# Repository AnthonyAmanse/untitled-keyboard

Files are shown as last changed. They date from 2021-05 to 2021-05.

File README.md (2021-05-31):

# Untitled Keyboard

This is a choc only wireless split keyboard with pro micro compatible sockets. It's inspired by the Sofle, Lily58, Corne, ... keyboards. It has Kailh choc spacings (18 mm x 17 mm). Keycaps I'm using are MBK choc keycaps which has a size of 17.5 x 16.5. I didn't add support for encoder to make it a bit lighter. Pinky columns has a 0.5u vertical offset to make it more comfortable (at least for me). Bottom row has 2 x 1.5u keys with an angle. I thought this would make the thumb cluster more comfortable and reachable. In my experience with this keyboard, the thumb keys are more comfortable when the keyboard is tented. OLED is supported as well - make sure you have a big battery as it consumes a lot of power. I'm using 2000 mAh. This should last me 3-4 weeks based on [ZMK's power profiler](https://zmkfirmware.dev/power-profiler).

The pro micro socket has a bit more width spacing to support the bluemicro840's 20mm width. I've only tested this keyboard with ZMK firmware but it should work for QMK as well since I've put in a slot for the TRRS jacks. Keyboard doesn't have a name so feel free to remove or change the silkscreen on the PCB!

## Build log/guide

1. [Materials](docs/materials.md)
2. [Building the Keyboard](docs/buildguide.md)
3. [Firmware](docs/firmware.md)

## Photos

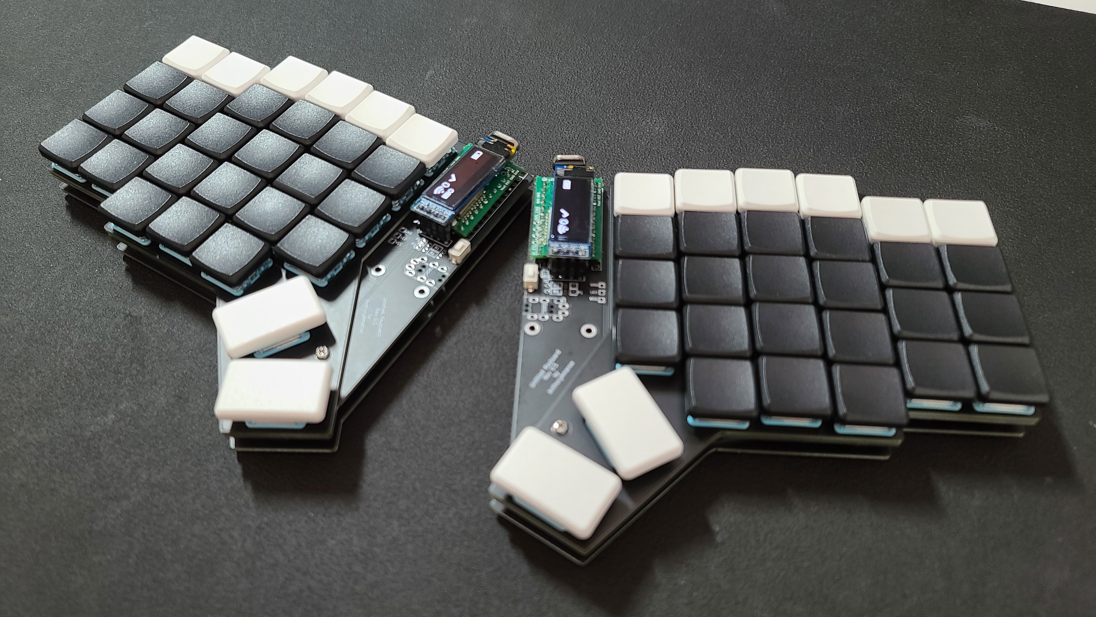
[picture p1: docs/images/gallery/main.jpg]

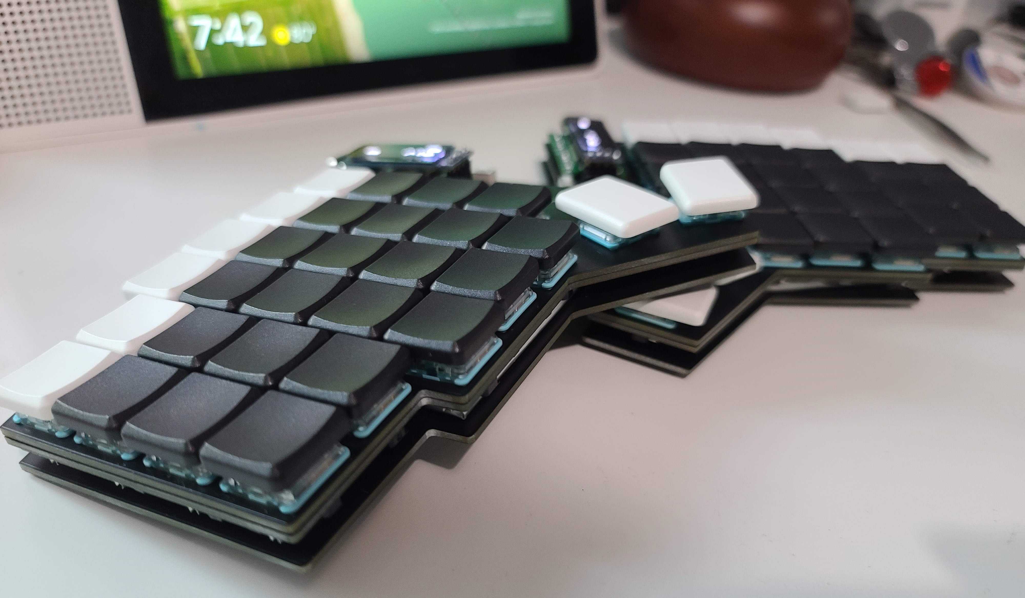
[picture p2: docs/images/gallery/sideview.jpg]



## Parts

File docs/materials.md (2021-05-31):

# Bill of Materials

#### 1. PCBs (main pcb and blank top/bottom plates)

The kicad project is open source. You can print using the gerbers and send them to a PCB manufacterer. I used JLCPCB for my prototypes.

#### 2. Pair of Microcontrollers

I used a pair of BlueMicro840 from https://store.jpconstantineau.com/

You can also use a nice!nano or nrfmicro. They should already have board definitions in ZMK. You can also use a non-wireless pro micro for use with QMK instead. You can grab an Elite C from [MKUltra](https://mkultra.click/elite-c-v4/) or the cheaper pro micro with micro usb.

#### 3. 58 pcs of Diodes smd 1n4148w sod 123

You can grab some on ebay or amazon. [Amazon](https://www.amazon.com/gp/product/B079KJX5J9) | [Ebay](https://www.ebay.com/itm/293687783598)
#### 4. 58 pcs of Kailh choc hot swap socket

I got some from MKUltra since I can buy the choc switches and MBK keycaps from them as well. [MKUltra](https://mkultra.click/kailh-hotswap-sockets)

#### 5. 2 pcs of 3.7v LiPo battery

You can find some on Ebay and Aliexpress. Make sure you get the ones that are 3mm thick. [Ebay](https://www.ebay.com/itm/224159433635)
#### 6. 10 pcs of M2 7mm stand-offs/spacers

To fit a 3mm battery between the pcb and bottom plate, you should use 7mm spacers. [Ebay](https://www.ebay.com/itm/174331139173)

#### 7. 20 pcs of M2 5mm screws 

5mm is tha maximum length you can use if you're using 7mm spacers. Take note that PCBs are 1.6mm thick [Ebay](https://www.ebay.com/itm/174466711363)

#### 8. 2 pcs of Momentary Tactile Pushbutton

Got some from Ebay. [Ebay](https://www.ebay.com/itm/254595728722)
#### 9. 4 pcs of 1x12 female pin headers and same amount for male pins

I grabbed some from LittleKeyboards. There's also some on Amazon but they'r a bit thicker. [LittleKeyboards](https://www.littlekeyboards.com/products/mill-max-ultra-low-profile-sockets?variant=39323794800707) | [Amazon](https://www.amazon.com/gp/product/B07BS126FK)
#### 10. 2 pcs of 1x4 pin headers for oled

I used the one's I got from Amazon. [Amazon](https://www.amazon.com/gp/product/B07BS126FK)

#### 11. 2 pcs of OLED 0.91 inch 128x32

I used the one I had from a Sofle Kit. You can find some on Amazon, Ebay, Aliexpress.

#### 12. Adhesive rubber feet

You will need to use some because the screws on the bottom will be the one touching your desk. I bought these from Amazon. [Amazon](https://www.amazon.com/gp/product/B07XXJZQMS)

#### 13. 2 pcs of TRRS jack (if you want this to be wired with QMK firmware)

You can find some on Amazon, Ebay, Aliexpress.

Link to the build guide:
[Build Guide](buildguide.md)

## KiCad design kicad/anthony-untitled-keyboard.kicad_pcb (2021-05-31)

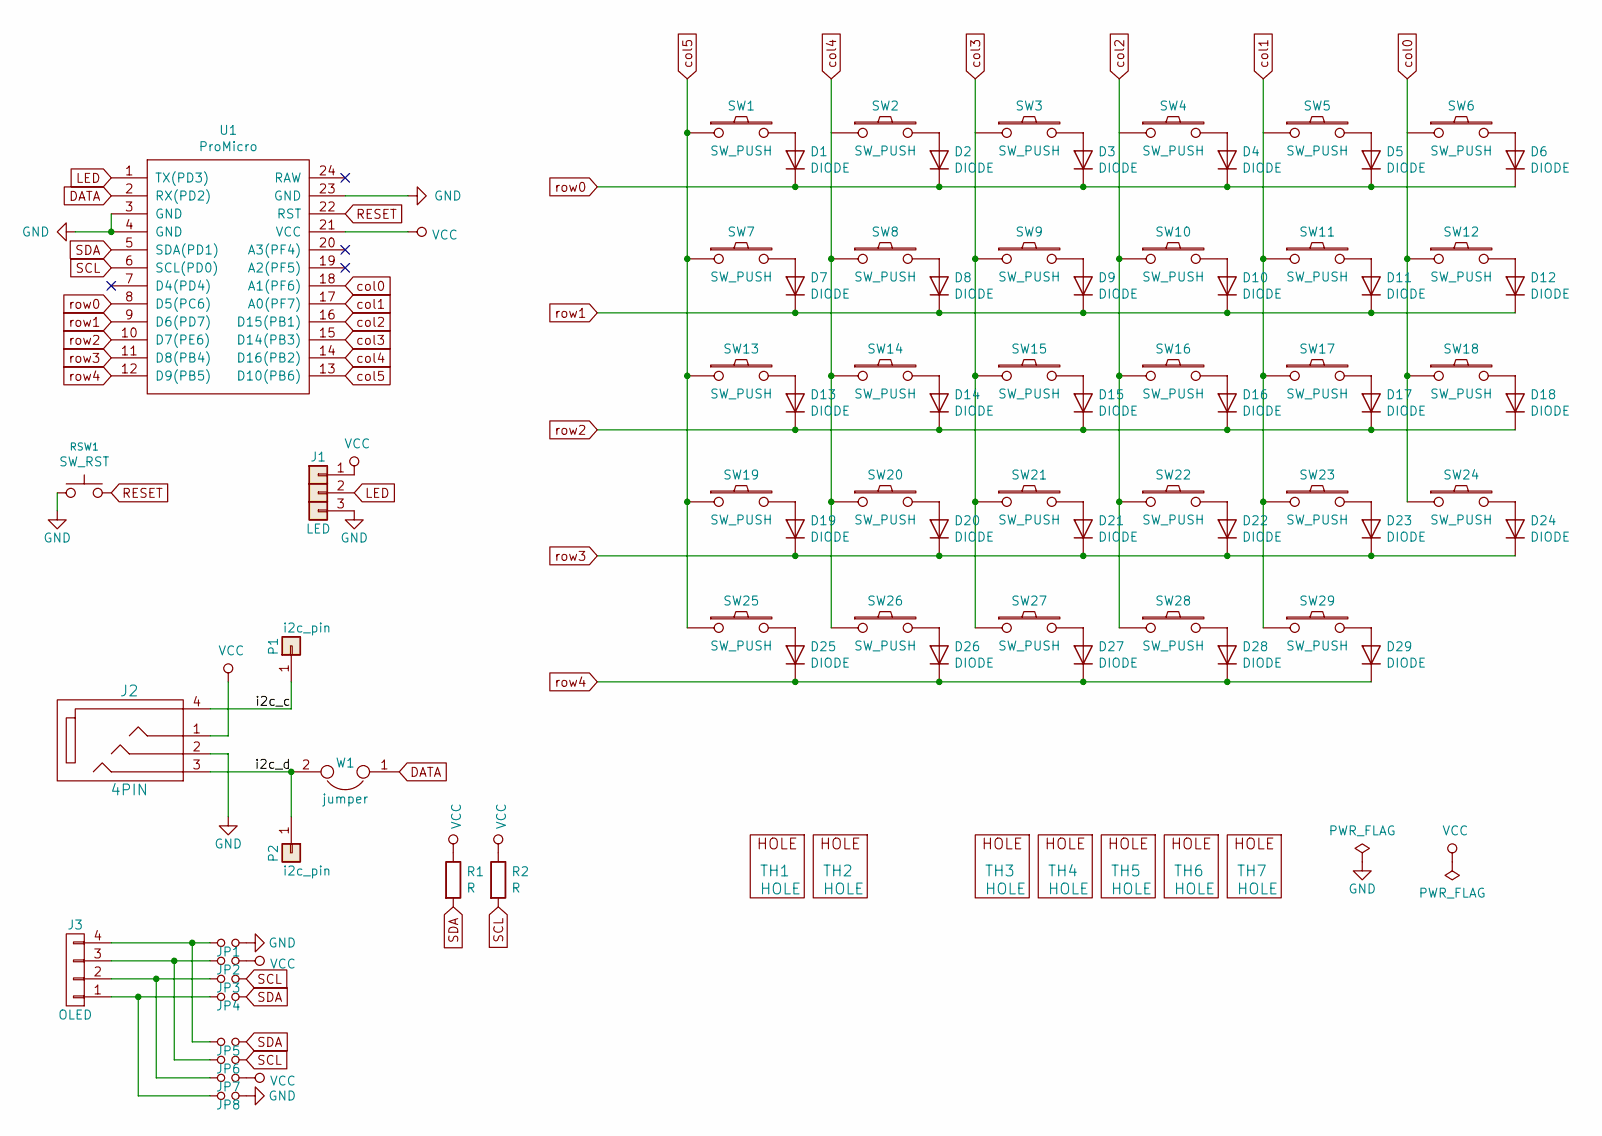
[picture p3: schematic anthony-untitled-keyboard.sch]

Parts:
D1, D2, D3, D4, D5, D6, D7, D8, D9, D10, D11, D12, D13, D14, D15, D16, D17, D18, D19, D20, D21, D22, D23, D24, D25, D26, D27, D28, D29: DIODE; Diode_SOD123
J1: LED
J2: 4PIN; MJ-4PP-9
J3: OLED; OLED_4Pin
JP1, JP2, JP3, JP4, JP5, JP6, JP7, JP8: Device_Jumper_NO_Small; Jumper
P1, P2: i2c_pin; 1pin_conn
R1, R2: R; RESISTOR_mini
RSW1: SW_RST; TACT_SWITCH_TVBP06
SW1, SW2, SW3, SW4, SW5, SW6, SW7, SW8, SW9, SW10, SW11, SW12, SW13, SW14, SW15, SW16, SW17, SW18, SW19, SW20, SW21, SW22, SW23, SW24, SW25, SW26, SW27, SW28, SW29: SW_PUSH; Kailh_socket_PG1350_reversible
TH1, TH2: HOLE; M2_HOLE_PCB
TH3, TH4, TH5, TH6, TH7: HOLE; HOLE_M2_TH
U1: ProMicro
W1: jumper; jumper_data

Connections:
/i2c_c: J2.4, P1.1
/i2c_d: J2.3, P2.1, W1.2
DATA: U1.2 (RX(PD2)), W1.1
GND: J1.3, J2.2, JP1.2, JP8.2, RSW1.1, U1.3 (GND), U1.4 (GND), U1.23 (GND)
LED: J1.2, U1.1 (TX(PD3))
unnamed: D1.2 (A), SW1.2
unnamed: D2.2 (A), SW2.2
unnamed: D3.2 (A), SW3.2
unnamed: D4.2 (A), SW4.2
unnamed: D5.2 (A), SW5.2
unnamed: D6.2 (A), SW6.2
unnamed: D7.2 (A), SW7.2
unnamed: D8.2 (A), SW8.2
unnamed: D9.2 (A), SW9.2
unnamed: D10.2 (A), SW10.2
unnamed: D11.2 (A), SW11.2
unnamed: D12.2 (A), SW12.2
unnamed: D13.2 (A), SW13.2
unnamed: D14.2 (A), SW14.2
unnamed: D15.2 (A), SW15.2
unnamed: D16.2 (A), SW16.2
unnamed: D17.2 (A), SW17.2
unnamed: D18.2 (A), SW18.2
unnamed: D19.2 (A), SW19.2
unnamed: D20.2 (A), SW20.2
unnamed: D21.2 (A), SW21.2
unnamed: D22.2 (A), SW22.2
unnamed: D23.2 (A), SW23.2
unnamed: D24.2 (A), SW24.2
unnamed: D25.2 (A), SW25.2
unnamed: D26.2 (A), SW26.2
unnamed: D27.2 (A), SW27.2
unnamed: D28.2 (A), SW28.2
unnamed: D29.2 (A), SW29.2
unnamed: J3.1, JP4.1, JP8.1
unnamed: J3.2, JP3.1, JP7.1
unnamed: J3.3, JP2.1, JP6.1
unnamed: J3.4, JP1.1, JP5.1
RESET: RSW1.2, U1.22 (RST)
SCL: JP3.2, JP6.2, R2.2, U1.6 (SCL(PD0))
SDA: JP4.2, JP5.2, R1.2, U1.5 (SDA(PD1))
VCC: J1.1, J2.1, JP2.2, JP7.2, R1.1, R2.1, U1.21 (VCC)
col0: SW6.1, SW12.1, SW18.1, SW24.1, U1.18 (A1(PF6))
col1: SW5.1, SW11.1, SW17.1, SW23.1, SW29.1, U1.17 (A0(PF7))
col2: SW4.1, SW10.1, SW16.1, SW22.1, SW28.1, U1.16 (D15(PB1))
col3: SW3.1, SW9.1, SW15.1, SW21.1, SW27.1, U1.15 (D14(PB3))
col4: SW2.1, SW8.1, SW14.1, SW20.1, SW26.1, U1.14 (D16(PB2))
col5: SW1.1, SW7.1, SW13.1, SW19.1, SW25.1, U1.13 (D10(PB6))
row0: D1.1 (K), D2.1 (K), D3.1 (K), D4.1 (K), D5.1 (K), D6.1 (K), U1.8 (D5(PC6))
row1: D7.1 (K), D8.1 (K), D9.1 (K), D10.1 (K), D11.1 (K), D12.1 (K), U1.9 (D6(PD7))
row2: D13.1 (K), D14.1 (K), D15.1 (K), D16.1 (K), D17.1 (K), D18.1 (K), U1.10 (D7(PE6))
row3: D19.1 (K), D20.1 (K), D21.1 (K), D22.1 (K), D23.1 (K), D24.1 (K), U1.11 (D8(PB4))
row4: D25.1 (K), D26.1 (K), D27.1 (K), D28.1 (K), D29.1 (K), U1.12 (D9(PB5))

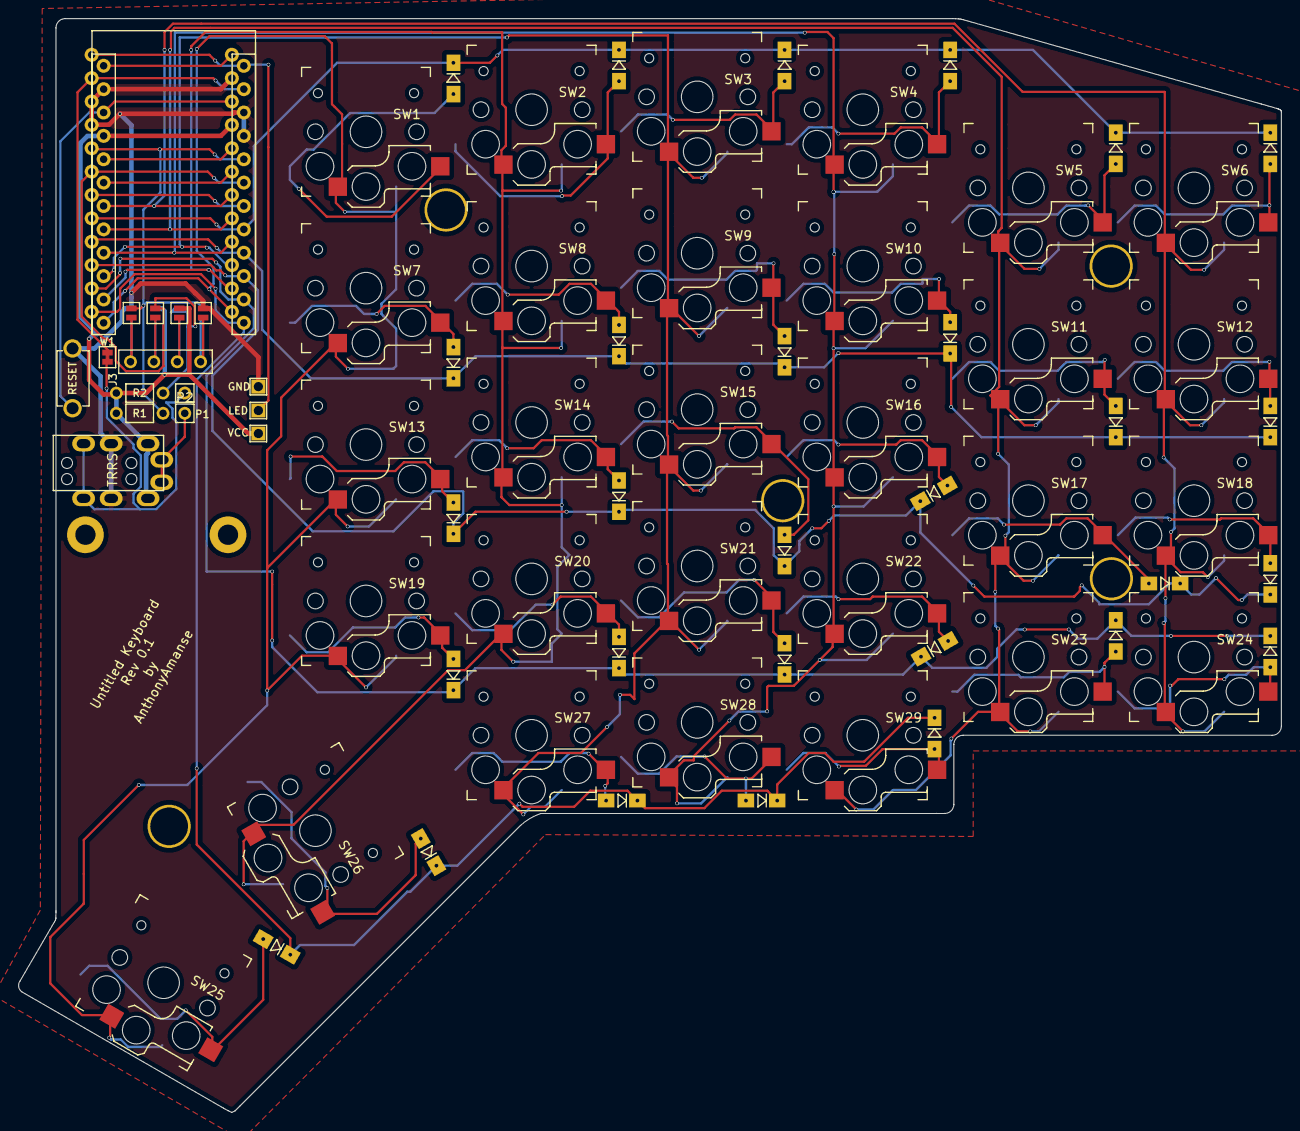
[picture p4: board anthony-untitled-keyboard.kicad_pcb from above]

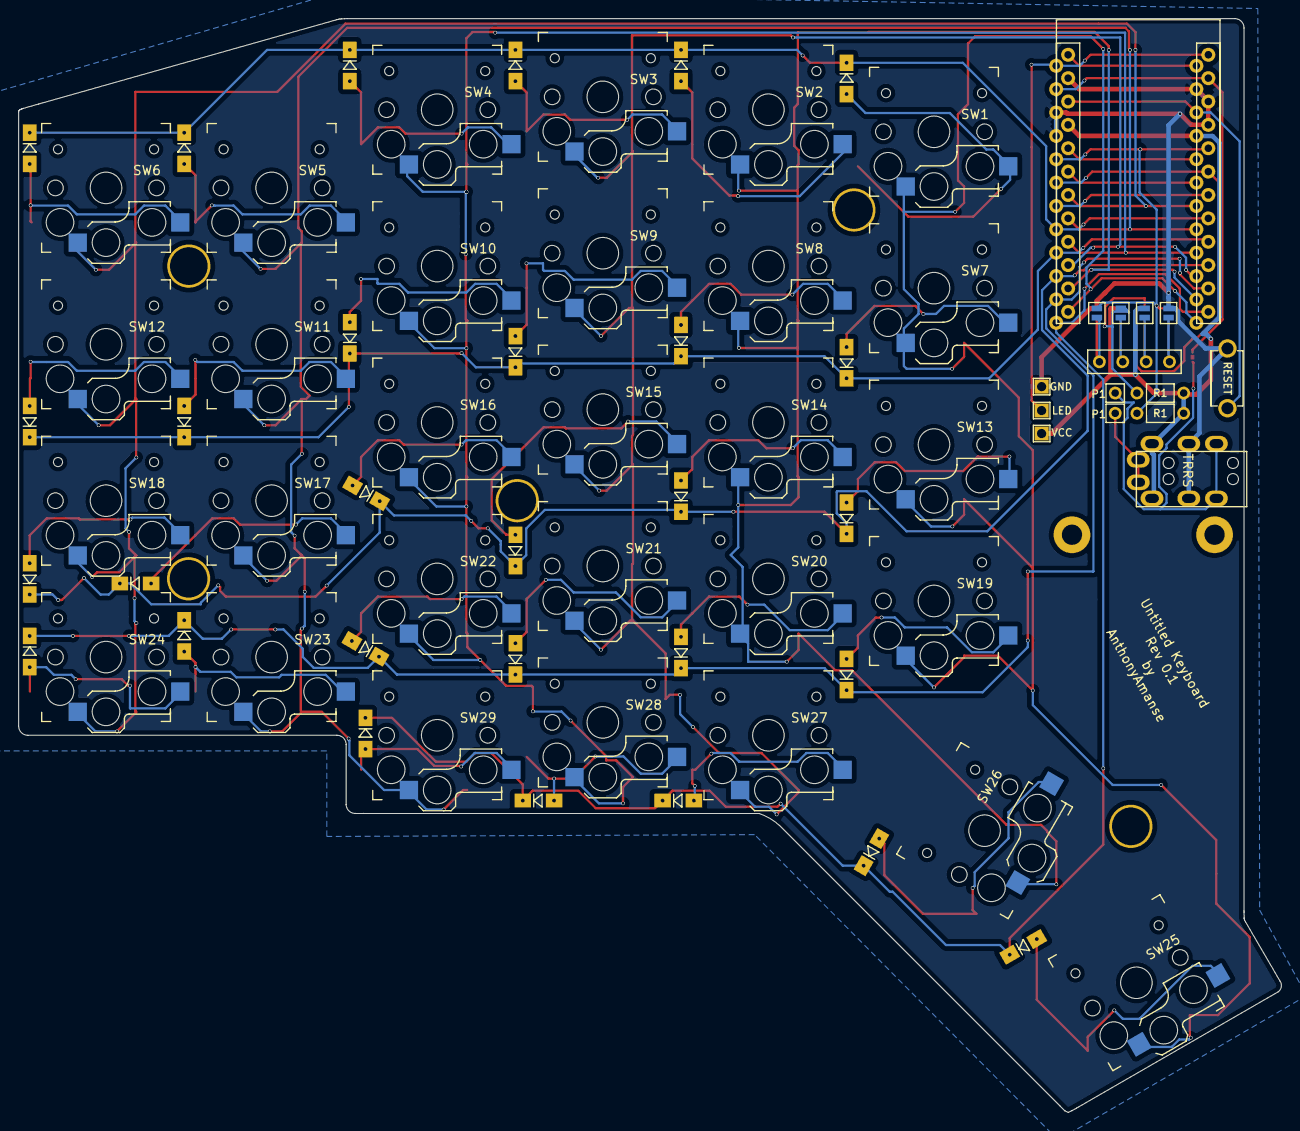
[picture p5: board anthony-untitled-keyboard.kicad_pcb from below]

Board: 2 copper layers, 137.3 x 118.9 mm, 83 parts (5 on the bottom side), 53 nets.

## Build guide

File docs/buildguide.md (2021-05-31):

# Build guide

The build process is mostly similar to the Sofle, Lily58, Corne keyboards.

Link to the bill of materials:
[materials](materials.md)

## Table of Contents

1. [Identify left and right PCBs](#1-identify-left-and-right-pcbs)
2. [Soldering the Diodes](#2-Soldering-the-Diodes)
3. [Soldering the Kailh Choc Hot swap sockets](#3-Soldering-the-Kailh-Choc-Hot-swap-sockets)
4. [Soldering the reset switch](#4-Soldering-the-reset-switch)
5. [Bridge pads for OLED](#5-Bridge-pads-for-OLED)
6. [Solder the pin headers](#6-Solder-the-pin-headers)
7. [Socket the microcontroller](#7-socket-the-microcontroller)
8. [Putting the switch plates](#8-Putting-the-switch-plates)
9. [Solder battery wires](#9-Solder-battery-wires)
10. [Putting the bottom plates](#10-Putting-the-bottom-plates)

#### 1. Identify left and right PCBs

The PCBs are reversible so you can use either for left and right. You will need to choose which one will be your left and right side. Then, take note or mark which one is your front and back on both sides of the keyboard.
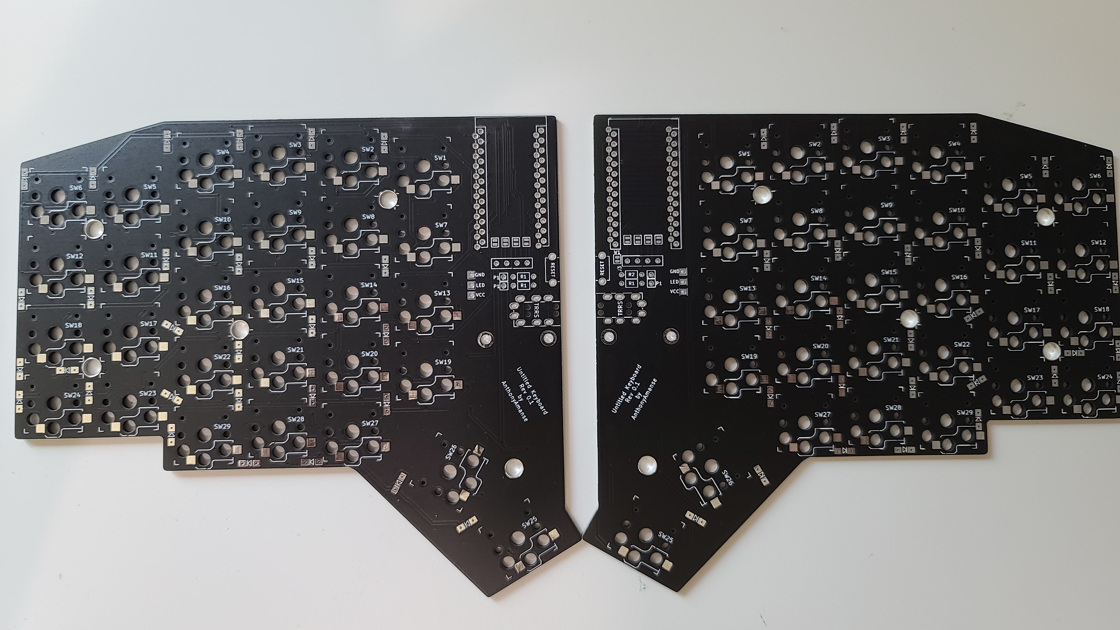
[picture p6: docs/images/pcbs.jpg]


#### 2. Soldering the Diodes
(BACK of the PCB)

There are 29 diodes for each side. The diodes will be soldered at the back of the pcb. **Orientation matters for the diode**. The diagram below shows the correct position for your diode.

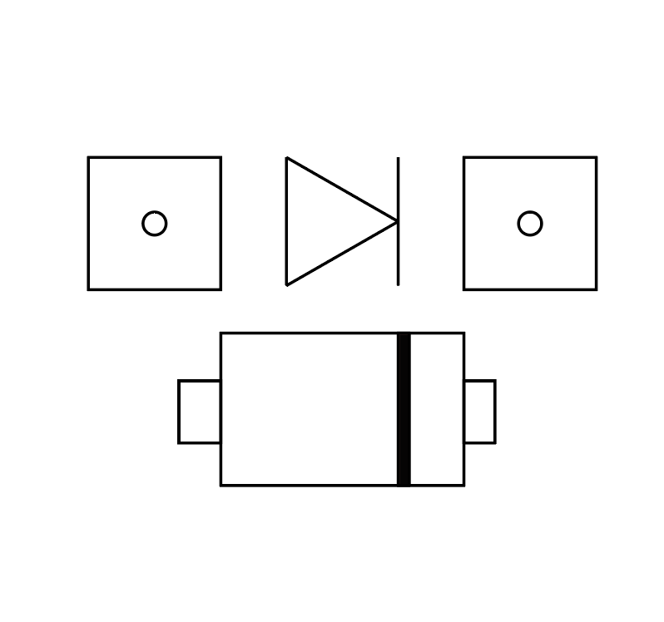
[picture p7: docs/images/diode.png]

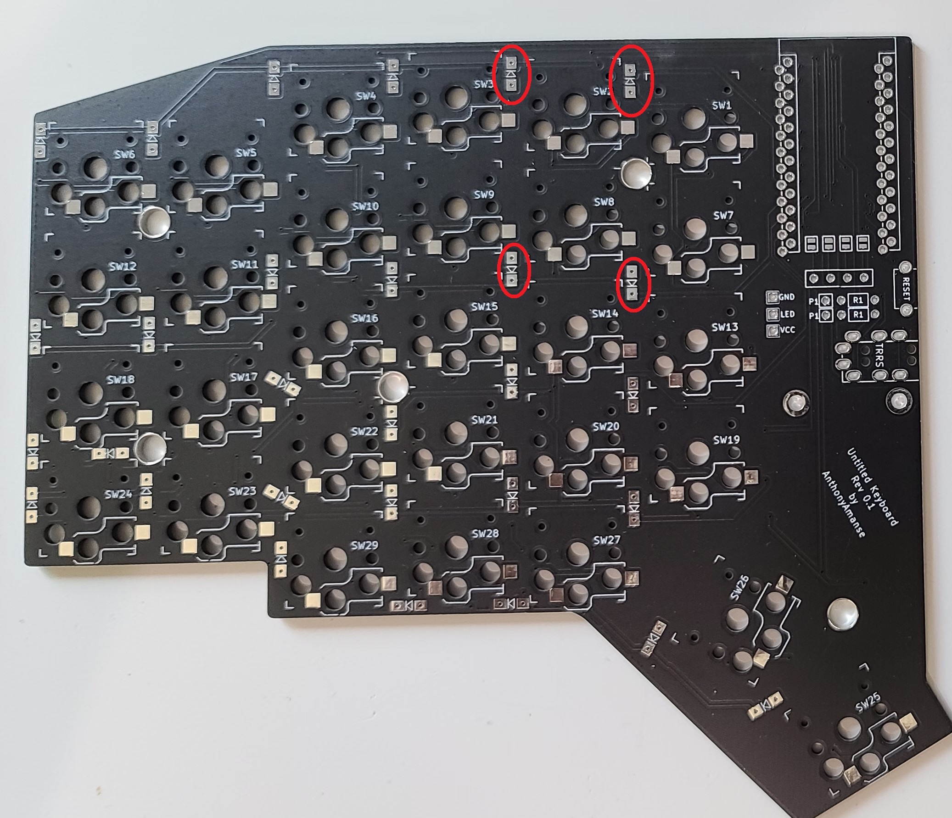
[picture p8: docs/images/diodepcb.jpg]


An easy way to solder SMD diodes is to solder one pad first (without the diode). Then place the diode and heat up the pad. That would stick one of the sides of the diode, then you can easily add solder to the other side of the diode.

#### 3. Soldering the Kailh Choc Hot swap sockets
(BACK of the PCB)

Orientation doesn't matter here but make sure they are placed at the back of your PCB - same as your diodes. Use the same technique from the previous step to easily solder in place. There are 29 sockets for each side.

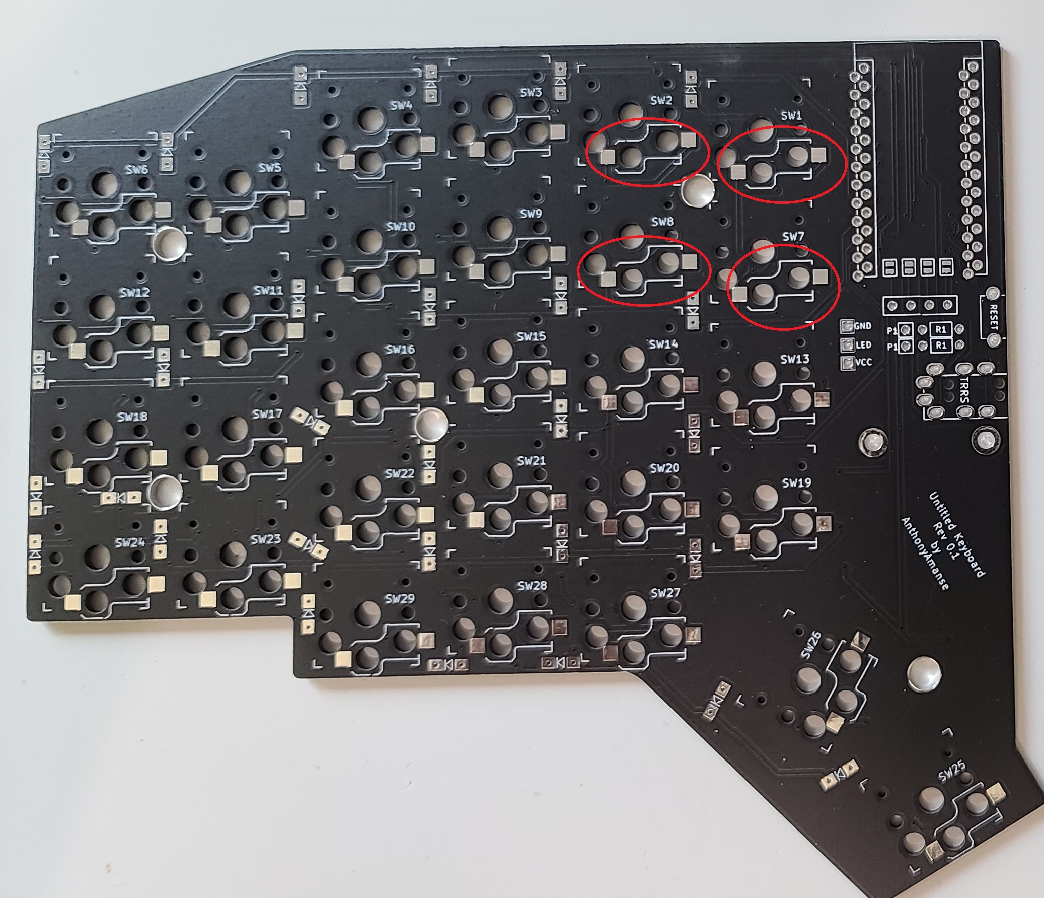
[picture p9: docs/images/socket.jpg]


#### 4. Soldering the reset switch
(FRONT of the PCB)

The reset switch should face in front of the pcb. Place the switch in its place and you can solder the pins from the back.

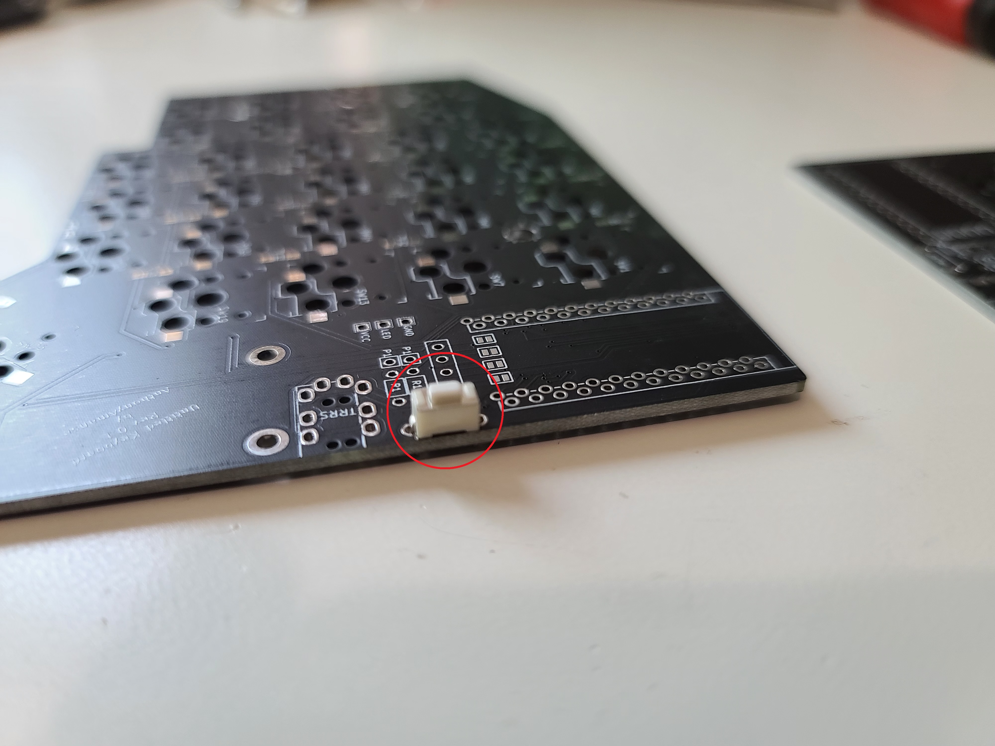
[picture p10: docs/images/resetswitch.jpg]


#### 5. Bridge pads for OLED
(FRONT of the PCB)

To use an OLED, create a bridge between these pads below. Make sure you do this in the FRONT side of your pcb.

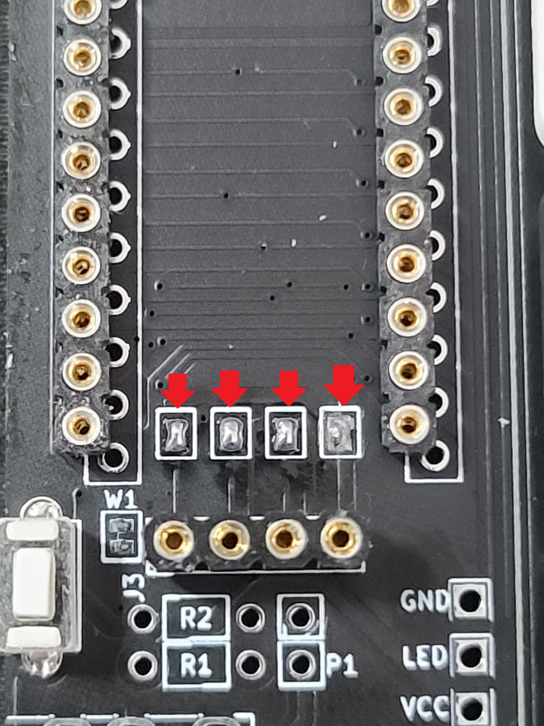
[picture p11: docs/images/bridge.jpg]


<!-- https://github.com/qmk/qmk_firmware/issues/7522 -->

#### 6. Solder the pin headers
(FRONT of the PCB)

The pin heades should be in front of the PCB. First, you will need to identify which of the 1x12 pinouts you will use. The image below shows which is the raw pinout. In my case, I used the columns with the red circle since I wanted my bluemicro840s to face up.

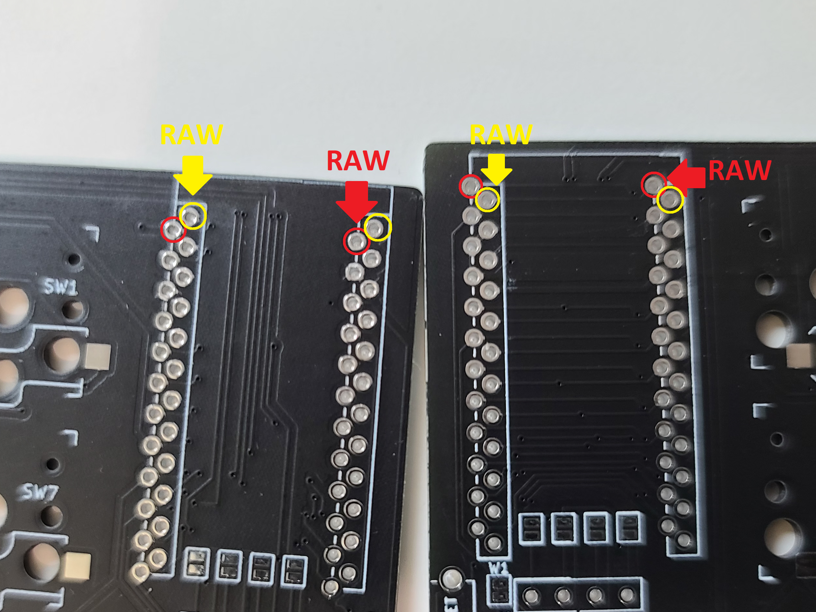
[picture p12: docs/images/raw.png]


#### 7. Socket the microcontroller

[Tips on how to socket a microcontroller](https://docs.splitkb.com/hc/en-us/articles/360011263059-How-do-I-socket-a-microcontroller-)

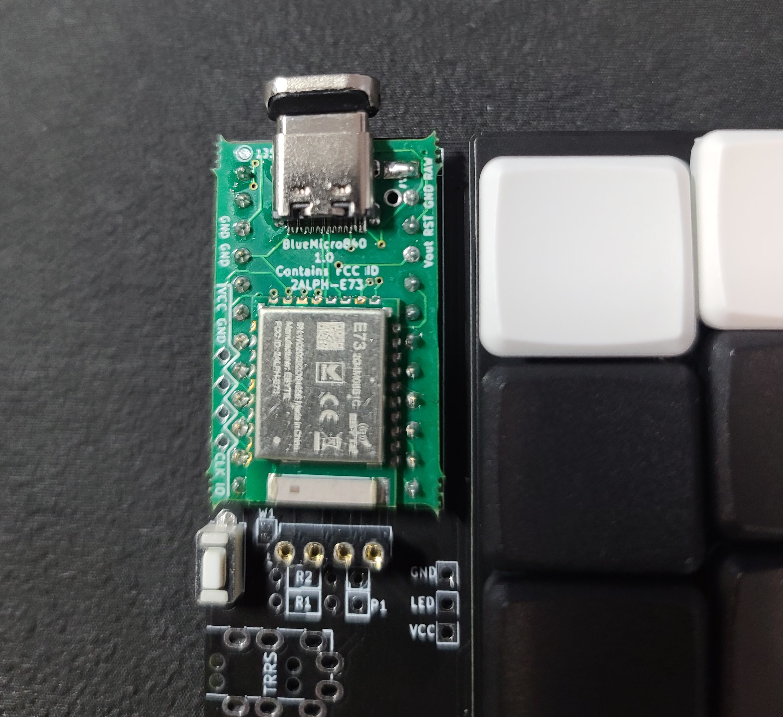
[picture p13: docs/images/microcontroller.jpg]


After socketing the microcontroller, de-attach it from the pcb before installing the battery.

#### 8. Putting the switch plates

You can now add the switch plate. You can use 5 switches initially to align and secure the switch plate to the PCB. Then proceed in installing all of them.

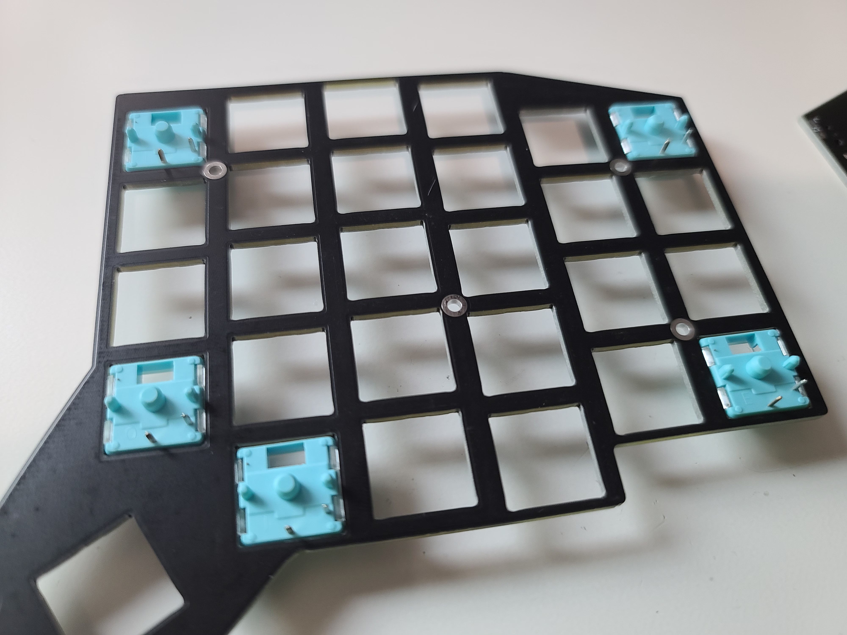
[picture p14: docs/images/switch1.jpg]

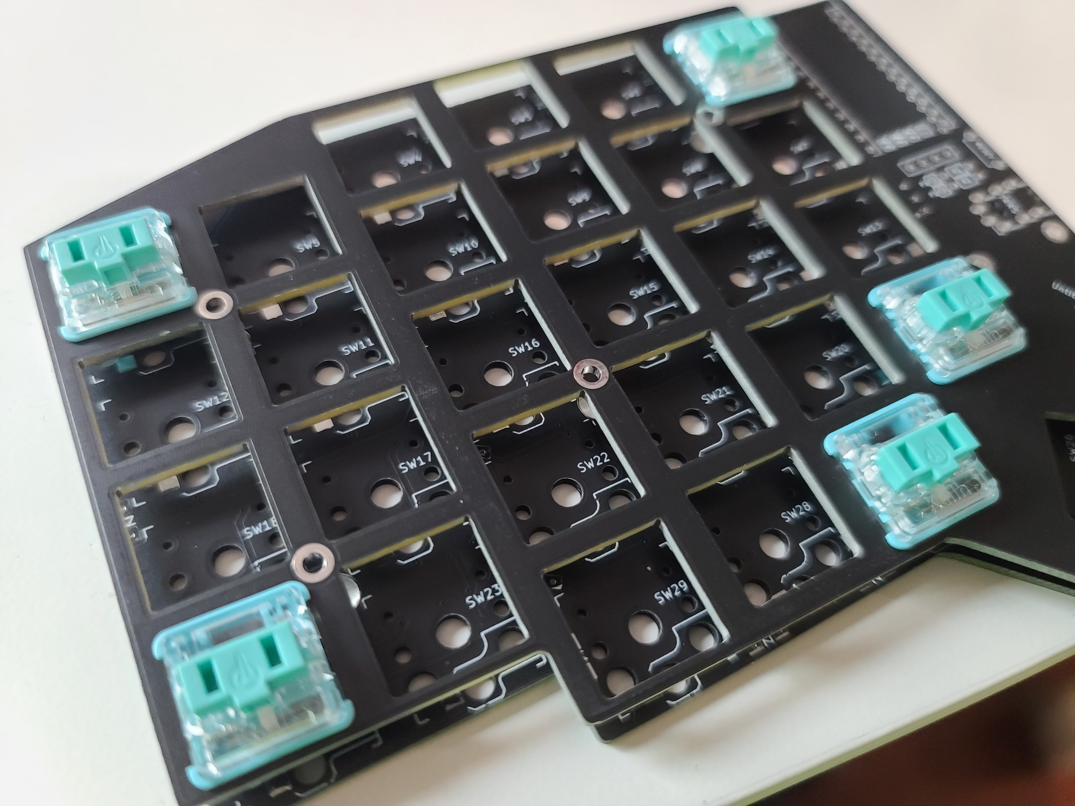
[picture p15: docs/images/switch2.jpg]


After securing the switch plate to the PCB, add the M2 spacers and screw them in the switch plate.

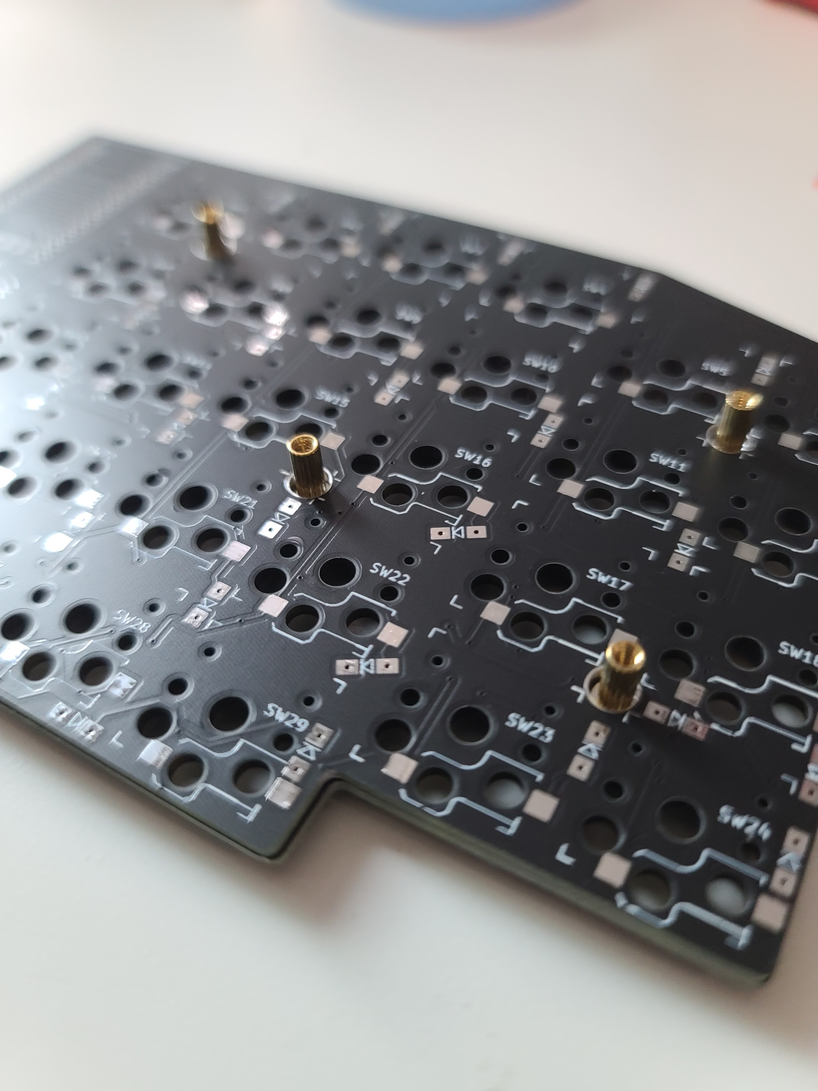
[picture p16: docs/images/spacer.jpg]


> You can omit the spacer in the middle to make space for your battery if it's big.

#### 9. Solder battery wires
(BACK of the PCB)

You will need attach a battery to use it wirelessly. Solder the RED wire to the RAW pin. The black wire to one of the GROUND pins. Using the image guide in Step 6, you can see where the RAW pinout is. Image below is how I have them set up.

> Make sure you don't have your microcontroller attached in your sockets to avoid short circuits.

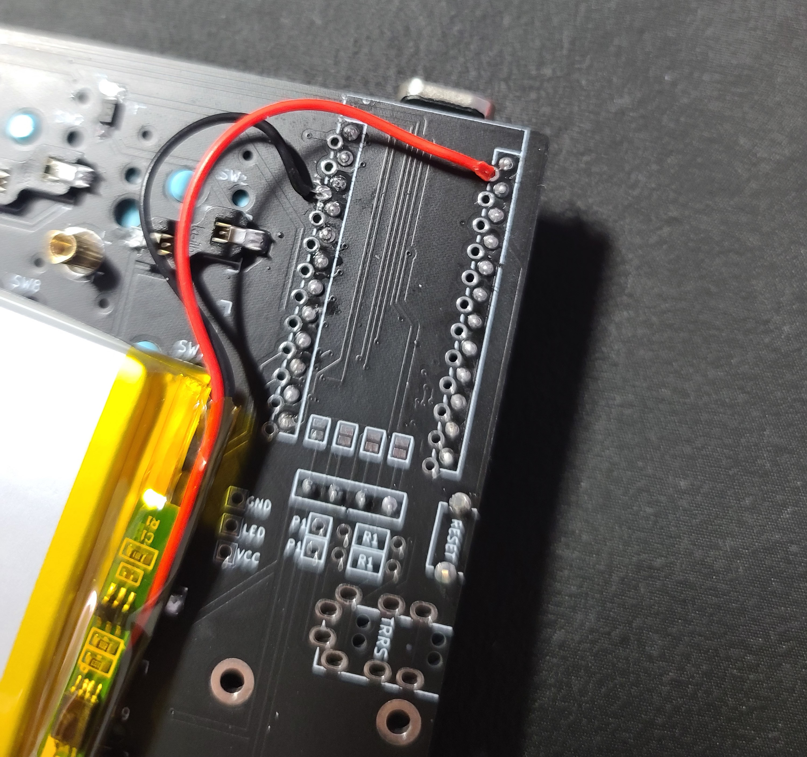
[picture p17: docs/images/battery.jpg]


#### 10. Putting the bottom plates

Screw in the M2 screws, add adhesive feet and you're done! Re-attach your microcontroller and you can now flash the ZMK firmware: [firmware.md](firmware.md)

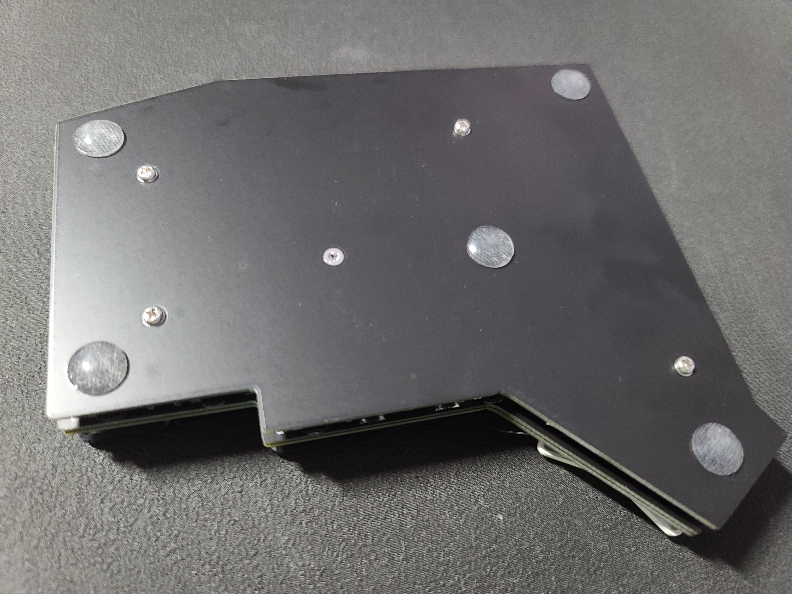
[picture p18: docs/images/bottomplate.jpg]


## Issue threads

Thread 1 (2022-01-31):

Easy Setup for ZMK Firmware

boysrbackintown, 2022-01-31:
Hi there,

I printed out and built the board from jlcpcb and am trying to get it to work with a nice!nano instead of the bluemicro, but I'm running into problems getting the firmware to work exactly. I see that the firmware guide is still under construction (I totally understand), but do you have a quick and dirty tips for getting it up and running in github using the Nice!Nano? Is there a comparable shield I could use to build out my own firmware?

Great work on the board by the way,
-C

machetie, 2022-03-29:
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

Hi,

i just ordered my parts and ordered the board with jlcpcb, have nice!nano`s on the way too, did you managed to use the firmware provided to flash the shields? If so, i just realised there are no power off switches, how do you turn off the keyboard?

3170, 2022-11-29:
Hi, here's my setup. Great work Anthony! E
https://github.com/3170/zmk-config

JostBrand, 2024-03-01:
Maybe also drop the info here directly.  Simply follow the tutorial on the ZMK website and choose the Lilly58 board.

There is no pad on the board for an on/off switch. I use nice!nano clones without OLEDs and enabled deep sleep. Currently this last for approximately 1 month without charging.

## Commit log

2021-05-31 Add gerber files
    This commit adds gerber files for the main pcb, switch plate, and bottom plate.
2021-05-31 Fix bom format
